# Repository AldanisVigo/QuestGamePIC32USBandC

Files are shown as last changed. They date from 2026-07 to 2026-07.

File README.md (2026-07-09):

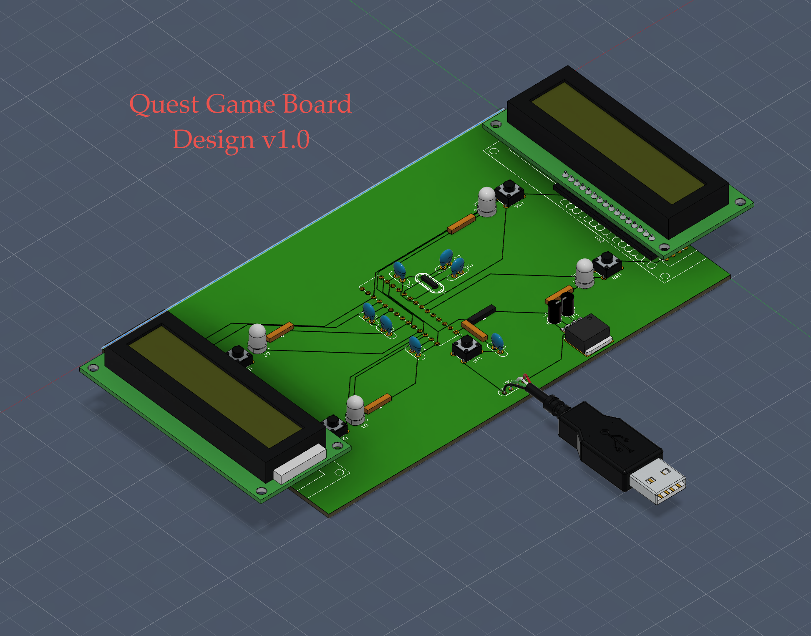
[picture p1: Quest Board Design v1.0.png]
Quest Board Design v1.0


# QuestGamePIC32USBandC

PIC32 USB CDC project with a GTK host game-controller app.

Current baseline:

- PIC32 enumerates as USB CDC serial.
- GTK host app connects over `/dev/cu.usbmodem*`.
- Host app edits and runs a 6-category, 5-row quiz board with a built-in starter trivia deck and A-D answers.
- Category selection alternates between players; the non-chooser is locked during board selection.
- PIC drives two I2C LCD backpacks: player 1 at `0x26`, player 2 at `0x23`.
- PIC stores the active question/options and scrolls player LCD text locally.
- PIC reads four active-low buttons on chip pins `6`, `7`, `11`, and `14`.
- PIC controls four button LEDs on chip pins `16`, `24`, `25`, and `26`, including solid/slow/fast game-state patterns.
- CDC control transfers are acknowledged correctly, so macOS opens the device without the previous timeout.

Default button and LED wiring:

| Button | Switch wire 1 | Switch wire 2 | LED + | LED - |
|---|---:|---:|---:|---:|
| P1 Next | chip pin `6` | `GND` | `3.3V through 470Ω` | chip pin `16` |
| P1 Select | chip pin `7` | `GND` | `3.3V through 470Ω` | chip pin `24` |
| P2 Next | chip pin `11` | `GND` | `3.3V through 470Ω` | chip pin `25` |
| P2 Select | chip pin `14` | `GND` | `3.3V through 470Ω` | chip pin `26` |

LED outputs are active-low: the PIC drives the LED pin low to turn the LED on.

Build:

```sh
cd quest.X
make build

cd ../host/quest-host
make
```

Firmware HEX:

```text
quest.X/dist/default/production/quest.X.production.hex
```

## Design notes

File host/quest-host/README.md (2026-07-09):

# Quest Game Controller

Standalone GTK+ 3 desktop app for running the PIC32 two-player quiz game over USB CDC serial.

## Build

Install GTK+ 3 and `pkg-config`, then build this host project:

```sh
cd host/quest-host
make
```

macOS with Homebrew:

```sh
brew install gtk+3 pkg-config
make
```

Debian/Ubuntu:

```sh
sudo apt install libgtk-3-dev pkg-config
make
```

## Run

```sh
./quest-game-host
```

The app scans common USB CDC serial device paths:

- macOS: `/dev/cu.usbmodem*`, `/dev/cu.usbserial*`
- Linux: `/dev/ttyACM*`, `/dev/ttyUSB*`

## Protocol

Host to PIC:

- `P1:<line1>|<line2>` updates player 1 LCD.
- `P2:<line1>|<line2>` updates player 2 LCD.
- `BOTH:<line1>|<line2>` updates both LCDs.
- `QSET:<question>|<A>|<B>|<C>|<D>` sends one question to the PIC; the PIC scrolls it locally.
- `QSEL:P1:A` or `QSEL:P2:D` changes the displayed answer option for one player.
- `LED:P1:NEXT:ON`, `OFF`, `SLOW`, or `FAST` controls player 1 next LED.
- `LED:P1:SELECT:ON`, `OFF`, `SLOW`, or `FAST` controls player 1 select LED.
- `LED:P2:NEXT:ON`, `OFF`, `SLOW`, or `FAST` controls player 2 next LED.
- `LED:P2:SELECT:ON`, `OFF`, `SLOW`, or `FAST` controls player 2 select LED.

PIC to host:

- `BTN:P1:NEXT`
- `BTN:P1:SELECT`
- `BTN:P2:NEXT`
- `BTN:P2:SELECT`

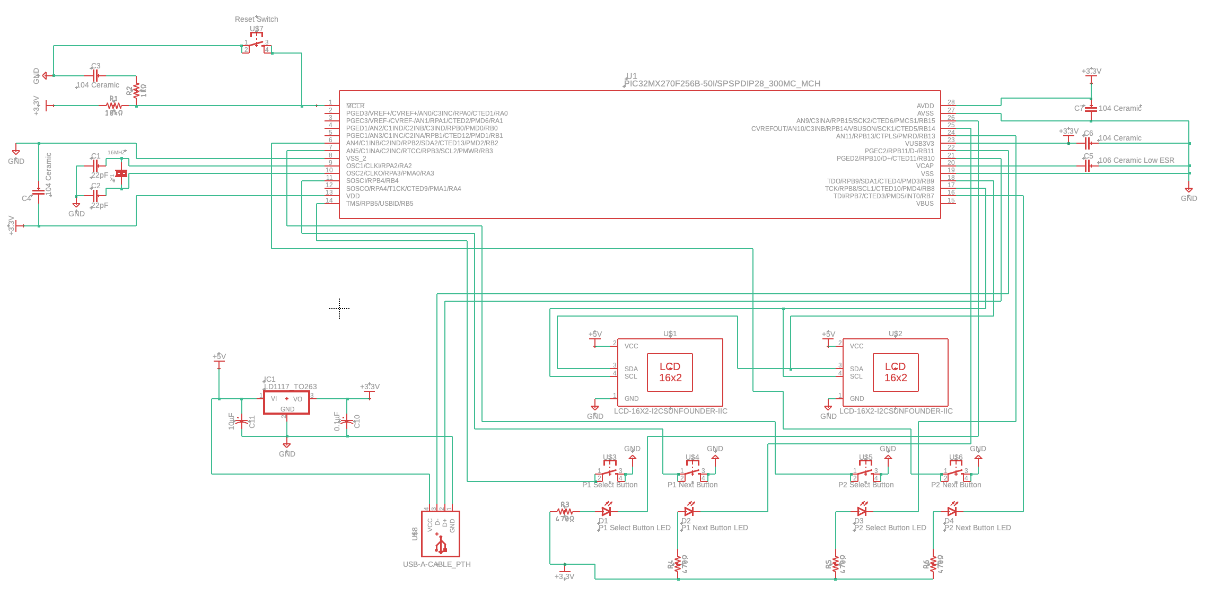
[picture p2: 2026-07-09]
Quest Board Schematic v1.0.png

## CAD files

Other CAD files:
Quest Game Through Hole Single PCB Design v1.0.f3d

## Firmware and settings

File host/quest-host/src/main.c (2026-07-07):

#include <gtk/gtk.h>
#include <stdarg.h>
#include <stdbool.h>
#include <stddef.h>
#include <stdio.h>
#include <string.h>

#include "serial_port.h"

#define SERIAL_BAUD_RATE 115200
#define CATEGORY_COUNT 6
#define AMOUNT_COUNT 5
#define OPTION_COUNT 4
#define PLAYER_COUNT 2
#define LCD_LINE_LENGTH 16
#define SERIAL_RX_BUFFER_SIZE 1024U

typedef enum
{
    GAME_MODE_BOARD,
    GAME_MODE_ANSWER
} GameMode;

typedef enum
{
    PLAYER_ACTION_NEXT,
    PLAYER_ACTION_SELECT
} PlayerAction;

typedef struct
{
    char question[320];
    char options[OPTION_COUNT][96];
    int correct_answer;
    bool used;
} QuestionCell;

typedef struct
{
    int cursor_index;
    int answer_index;
    int selected_answer;
    int score;
    bool answered;
    bool last_correct;
} PlayerState;

typedef struct
{
    GtkWidget *window;
    GtkComboBoxText *device_combo;
    GtkButton *connect_button;
    GtkLabel *status_label;
    GtkLabel *mode_label;
    GtkLabel *score_labels[PLAYER_COUNT];
    GtkLabel *player_status_labels[PLAYER_COUNT];
    GtkEntry *category_entries[CATEGORY_COUNT];
    GtkSpinButton *amount_spins[AMOUNT_COUNT];
    GtkButton *board_buttons[CATEGORY_COUNT][AMOUNT_COUNT];
    GtkLabel *editor_heading_label;
    GtkTextView *question_view;
    GtkTextBuffer *question_buffer;
    GtkEntry *option_entries[OPTION_COUNT];
    GtkComboBoxText *correct_combo;
    GtkButton *save_button;
    GtkButton *start_button;
    GtkButton *reset_button;
    GtkTextView *log_view;
    GtkTextBuffer *log_buffer;

    int serial_fd;
    guint read_timer_id;
    guint connect_watch_id;
    guint result_timeout_id;
    unsigned int connect_generation;
    gint64 connect_started_us;
    bool connecting;

    char serial_rx_buffer[SERIAL_RX_BUFFER_SIZE];
    size_t serial_rx_length;

    char categories[CATEGORY_COUNT][48];
    int amounts[AMOUNT_COUNT];
    QuestionCell cells[CATEGORY_COUNT][AMOUNT_COUNT];
    PlayerState players[PLAYER_COUNT];
    GameMode mode;
    int selected_category;
    int selected_amount;
    int active_category;
    int active_amount;
    int chooser_player;
} AppData;

typedef struct
{
    AppData *app;
    gchar *path;
    int fd;
    unsigned int generation;
    gint64 started_us;
    gint64 worker_started_us;
    gint64 open_returned_us;
    char error[160];
} ConnectRequest;

static gboolean poll_serial(gpointer user_data);
static void refresh_ui(AppData *app);
static void update_all_lcds(AppData *app);
static void load_editor_from_selected(AppData *app);
static void save_editor_to_selected(AppData *app);
static void handle_player_action(AppData *app, int player, PlayerAction action);

static long long elapsed_ms(gint64 start_us, gint64 end_us)
{
    if(start_us <= 0 || end_us < start_us)
    {
        return 0;
    }

    return (long long)((end_us - start_us) / 1000);
}

static GtkWidget *make_icon_label(const char *icon_name, const char *label)
{
    GtkWidget *box = gtk_box_new(GTK_ORIENTATION_HORIZONTAL, 6);
    GtkWidget *image = gtk_image_new_from_icon_name(icon_name, GTK_ICON_SIZE_BUTTON);
    GtkWidget *text = gtk_label_new(label);

    gtk_box_pack_start(GTK_BOX(box), image, FALSE, FALSE, 0);
    gtk_box_pack_start(GTK_BOX(box), text, FALSE, FALSE, 0);

    return box;
}

static void set_button_content(GtkButton *button, const char *icon_name, const char *label)
{
    GtkWidget *child = gtk_bin_get_child(GTK_BIN(button));

    if(child != NULL)
    {
        gtk_container_remove(GTK_CONTAINER(button), child);
    }

    gtk_container_add(GTK_CONTAINER(button), make_icon_label(icon_name, label));
    gtk_widget_show_all(GTK_WIDGET(button));
}

static GtkWidget *new_icon_button(const char *icon_name, const char *tooltip)
{
    GtkWidget *button = gtk_button_new_from_icon_name(icon_name, GTK_ICON_SIZE_BUTTON);
    gtk_widget_set_tooltip_text(button, tooltip);
    return button;
}

static GtkWidget *new_scrolled_text_view(GtkTextView **view, GtkTextBuffer **buffer, int height, bool editable)
{
    GtkWidget *scroll = gtk_scrolled_window_new(NULL, NULL);

    *view = GTK_TEXT_VIEW(gtk_text_view_new());
    *buffer = gtk_text_view_get_buffer(*view);

    gtk_text_view_set_wrap_mode(*view, GTK_WRAP_WORD_CHAR);
    gtk_text_view_set_editable(*view, editable);
    gtk_text_view_set_cursor_visible(*view, editable);
    gtk_container_add(GTK_CONTAINER(scroll), GTK_WIDGET(*view));
    gtk_widget_set_size_request(scroll, -1, height);

    return scroll;
}

static void set_status(AppData *app, const char *message)
{
    gtk_label_set_text(app->status_label, message);
}

static void append_log(AppData *app, const char *prefix, const char *message)
{
    GtkTextIter end;
    GtkTextMark *insert_mark;
    GDateTime *now;
    gchar *clock_text;
    char stamp[32];

    gtk_text_buffer_get_end_iter(app->log_buffer, &end);

    now = g_date_time_new_now_local();
    clock_text = g_date_time_format(now, "%H:%M:%S");
    snprintf(stamp, sizeof(stamp), "[%s.%03d] ", clock_text, g_date_time_get_microsecond(now) / 1000);

    gtk_text_buffer_insert(app->log_buffer, &end, stamp, -1);

    if(prefix != NULL)
    {
        gtk_text_buffer_insert(app->log_buffer, &end, prefix, -1);
    }

    gtk_text_buffer_insert(app->log_buffer, &end, message, -1);
    gtk_text_buffer_insert(app->log_buffer, &end, "\n", -1);

    insert_mark = gtk_text_buffer_get_insert(app->log_buffer);
    gtk_text_view_scroll_mark_onscreen(app->log_view, insert_mark);

    g_free(clock_text);
    g_date_time_unref(now);
}

static void append_logf(AppData *app, const char *prefix, const char *format, ...)
{
    va_list args;
    gchar *message;

    va_start(args, format);
    message = g_strdup_vprintf(format, args);
    va_end(args);

    append_log(app, prefix, message);
    g_free(message);
}

static const char *player_action_name(PlayerAction action)
{
    return action == PLAYER_ACTION_NEXT ? "NEXT" : "SELECT";
}

static const char *game_mode_name(GameMode mode)
{
    return mode == GAME_MODE_BOARD ? "board" : "answer";
}

static int next_player_index(int player)
{
    return (player + 1) % PLAYER_COUNT;
}

static void copy_text(char *dest, size_t dest_size, const char *source)
{
    if(source == NULL)
    {
        source = "";
    }

    g_strlcpy(dest, source, dest_size);
}

static int cell_index(int category, int amount)
{
    return (amount * CATEGORY_COUNT) + category;
}

static void cell_from_index(int index, int *category, int *amount)
{
    if(index < 0)
    {
        index = 0;
    }

    *category = index % CATEGORY_COUNT;
    *amount = index / CATEGORY_COUNT;
}

static QuestionCell *cell_at(AppData *app, int category, int amount)
{
    return &app->cells[category][amount];
}

static QuestionCell *selected_cell(AppData *app)
{
    return cell_at(app, app->selected_category, app->selected_amount);
}

static bool cell_is_available(AppData *app, int index)
{
    int category;
    int amount;

    if(index < 0 || index >= (CATEGORY_COUNT * AMOUNT_COUNT))
    {
        return false;
    }

    cell_from_index(index, &category, &amount);
    return !cell_at(app, category, amount)->used;
}

static int find_available_cell(AppData *app, int start_index, int direction)
{
    const int total = CATEGORY_COUNT * AMOUNT_COUNT;

    if(direction == 0)
    {
        direction = 1;
    }

    for(int step = 0; step < total; step++)
    {
        int index = (start_index + (step * direction)) % total;

        if(index < 0)
        {
            index += total;
        }

        if(cell_is_available(app, index))
        {
            return index;
        }
    }

    return -1;
}

static void reset_player_cursors(AppData *app)
{
    int first = find_available_cell(app, 0, 1);

    for(int player = 0; player < PLAYER_COUNT; player++)
    {
        app->players[player].cursor_index = first;
        app->players[player].answer_index = 0;
        app->players[player].selected_answer = -1;
        app->players[player].answered = false;
        app->players[player].last_correct = false;
    }
}

static void game_init_content(AppData *app)
{
    typedef struct
    {
        const char *question;
        const char *options[OPTION_COUNT];
        int correct_answer;
    } DefaultQuestion;

    static const char *default_categories[CATEGORY_COUNT] =
    {
        "Science",
        "History",
        "Geography",
        "Movies",
        "Tech",
        "Games"
    };

    static const DefaultQuestion default_questions[CATEGORY_COUNT][AMOUNT_COUNT] =
    {
        {
            {
                "What gas do plants absorb from the air during photosynthesis?",
                { "Oxygen", "Carbon dioxide", "Nitrogen", "Helium" },
                1
            },
            {
                "What force pulls objects toward the center of Earth?",
                { "Magnetism", "Friction", "Gravity", "Electricity" },
                2
            },
            {
                "What is the chemical formula for water?",
                { "CO2", "H2O", "O2", "NaCl" },
                1
            },
            {
                "Which planet is often called the Red Planet?",
                { "Venus", "Jupiter", "Mars", "Mercury" },
                2
            },
            {
                "What is the smallest basic unit of living organisms?",
                { "Atom", "Cell", "Organ", "Tissue" },
                1
            }
        },
        {
            {
                "Who was the first president of the United States?",
                { "John Adams", "Thomas Jefferson", "George Washington", "James Madison" },
                2
            },
            {
                "Which wall fell in 1989, becoming a symbol of the Cold War ending?",
                { "Hadrian's Wall", "Berlin Wall", "Great Wall", "Western Wall" },
                1
            },
            {
                "Which ancient civilization built the pyramids at Giza?",
                { "Romans", "Egyptians", "Vikings", "Aztecs" },
                1
            },
            {
                "Which American document begins with the words 'We the People'?",
                { "Declaration of Independence", "Bill of Rights", "U.S. Constitution", "Gettysburg Address" },
                2
            },
            {
                "What ship carried the Pilgrims to New England in 1620?",
                { "Santa Maria", "Mayflower", "Endeavour", "Beagle" },
                1
            }
        },
        {
            {
                "What is the largest ocean on Earth?",
                { "Atlantic", "Indian", "Arctic", "Pacific" },
                3
            },
            {
                "Which country is famously shaped like a boot?",
                { "Italy", "Greece", "Chile", "Portugal" },
                0
            },
            {
                "Which river runs through Egypt and helped support its ancient civilization?",
                { "Amazon", "Danube", "Nile", "Ganges" },
                2
            },
            {
                "What is the capital city of Japan?",
                { "Kyoto", "Tokyo", "Osaka", "Sapporo" },
                1
            },
            {
                "What is the highest mountain above sea level?",
                { "K2", "Denali", "Mount Everest", "Kilimanjaro" },
                2
            }
        },
        {
            {
                "Which movie franchise is known for Jedi and lightsabers?",
                { "Star Trek", "Star Wars", "The Matrix", "Avatar" },
                1
            },
            {
                "What is the name of Harry Potter's school?",
                { "Hogwarts", "Narnia", "Nevermore", "Rivendell" },
                0
            },
            {
                "Which Disney movie features sisters named Elsa and Anna?",
                { "Moana", "Frozen", "Tangled", "Brave" },
                1
            },
            {
                "What fictional city is protected by Batman?",
                { "Metropolis", "Gotham City", "Central City", "Star City" },
                1
            },
            {
                "Which actor made the line 'I'll be back' famous in The Terminator?",
                { "Bruce Willis", "Sylvester Stallone", "Arnold Schwarzenegger", "Harrison Ford" },
                2
            }
        },
        {
            {
                "What does CPU stand for?",
                { "Central Processing Unit", "Computer Power Utility", "Core Program Update", "Control Panel Unit" },
                0
            },
            {
                "Binary numbers use which base?",
                { "Base 8", "Base 10", "Base 16", "Base 2" },
                3
            },
            {
                "Which protocol is the foundation for loading most web pages?",
                { "HTTP", "MIDI", "SMTP", "GPS" },
                0
            },
            {
                "What sensor measures acceleration?",
                { "Thermistor", "Accelerometer", "Barometer", "Photodiode" },
                1
            },
            {
                "What does ROM usually stand for in electronics?",
                { "Random Output Module", "Read-Only Memory", "Remote Operating Mode", "Runtime Object Map" },
                1
            }
        },
        {
            {
                "How many points is a touchdown worth in American football?",
                { "3", "6", "7", "10" },
                1
            },
            {
                "Which chess piece moves in an L shape?",
                { "Bishop", "Rook", "Knight", "Queen" },
                2
            },
            {
                "How often are the Summer Olympic Games normally held?",
                { "Every 2 years", "Every 3 years", "Every 4 years", "Every 5 years" },
                2
            },
            {
                "Which board game has players buy properties and collect rent?",
                { "Monopoly", "Risk", "Clue", "Scrabble" },
                0
            },
            {
                "In tennis, what is the score called after deuce when one player wins the next point?",
                { "Match", "Break", "Advantage", "Set" },
                2
            }
        }
    };

    for(int category = 0; category < CATEGORY_COUNT; category++)
    {
        copy_text(app->categories[category], sizeof(app->categories[category]), default_categories[category]);
    }

    for(int amount = 0; amount < AMOUNT_COUNT; amount++)
    {
        app->amounts[amount] = (amount + 1) * 100;
    }

    for(int category = 0; category < CATEGORY_COUNT; category++)
    {
        for(int amount = 0; amount < AMOUNT_COUNT; amount++)
        {
            QuestionCell *cell = cell_at(app, category, amount);
            const DefaultQuestion *question = &default_questions[category][amount];

            copy_text(cell->question, sizeof(cell->question), question->question);
            for(int option = 0; option < OPTION_COUNT; option++)
            {
                copy_text(cell->options[option],
                          sizeof(cell->options[option]),
                          question->options[option]);
            }
            cell->correct_answer = question->correct_answer;
            cell->used = false;
        }
    }

    app->selected_category = 0;
    app->selected_amount = 0;
    app->active_category = 0;
    app->active_amount = 0;
    app->mode = GAME_MODE_BOARD;
    app->chooser_player = 0;
    app->players[0].score = 0;
    app->players[1].score = 0;
    reset_player_cursors(app);
}

static void lcd_clean_line(const char *source, char *dest)
{
    size_t length = 0;

    if(source == NULL)
    {
        source = "";
    }

    while(source[length] != '\0' && length < LCD_LINE_LENGTH)
    {
        unsigned char c = (unsigned char)source[length];

        if(c == '|' || c == '\r' || c == '\n' || c == '\t')
        {
            dest[length] = ' ';
        }
        else if(c >= 32U && c <= 126U)
        {
            dest[length] = (char)c;
        }
        else
        {
            dest[length] = '?';
        }

        length++;
    }

    dest[length] = '\0';
}

static void send_lcd_lines_internal(AppData *app,
                                    int player,
                                    const char *line1,
                                    const char *line2,
                                    bool log_command)
{
    char clean1[LCD_LINE_LENGTH + 1U];
    char clean2[LCD_LINE_LENGTH + 1U];
    char command[64];
    char preview[64];
    char error[160];

    if(app->serial_fd < 0)
    {
        return;
    }

    lcd_clean_line(line1, clean1);
    lcd_clean_line(line2, clean2);

    snprintf(command, sizeof(command), "P%d:%s|%s\n", player + 1, clean1, clean2);
    g_strlcpy(preview, command, sizeof(preview));
    g_strchomp(preview);

    if(log_command)
    {
        append_logf(app, "> ", "%s", preview);
    }

    if(pic_serial_write_all(app->serial_fd, command, strlen(command), 350, error, sizeof(error)) != 0)
    {
        append_log(app, "! ", error);
        set_status(app, "LCD write failed");
    }
}

static void send_led_command(AppData *app, int player, const char *button_name, const char *mode)
{
    char command[40];
    char error[160];

    if(app->serial_fd < 0)
    {
        return;
    }

    snprintf(command, sizeof(command), "LED:P%d:%s:%s\n",
             player + 1,
             button_name,
             mode);

    if(pic_serial_write_all(app->serial_fd, command, strlen(command), 250, error, sizeof(error)) != 0)
    {
        append_log(app, "! ", error);
        set_status(app, "LED write failed");
    }
}

static void append_pic_protocol_field(GString *command, const char *text)
{
    if(text == NULL)
    {
        text = "";
    }

    for(const unsigned char *cursor = (const unsigned char *)text; *cursor != '\0'; cursor++)
    {
        unsigned char c = *cursor;

        if(c == '|' || c == '\r' || c == '\n' || c == '\t')
        {
            g_string_append_c(command, ' ');
        }
        else if(c >= 32U && c <= 126U)
        {
            g_string_append_c(command, (char)c);
        }
        else
        {
            g_string_append_c(command, '?');
        }
    }
}

static void send_question_set_command(AppData *app)
{
    QuestionCell *cell = cell_at(app, app->active_category, app->active_amount);
    GString *command;
    char error[160];

    if(app->serial_fd < 0)
    {
        return;
    }

    command = g_string_new("QSET:");
    append_pic_protocol_field(command, cell->question);

    for(int option = 0; option < OPTION_COUNT; option++)
    {
        g_string_append_c(command, '|');
        append_pic_protocol_field(command, cell->options[option]);
    }

    g_string_append_c(command, '\n');
    append_logf(app, "> ", "QSET question/options (%zu byte(s))", command->len);

    if(pic_serial_write_all(app->serial_fd, command->str, command->len, 1500, error, sizeof(error)) != 0)
    {
        append_log(app, "! ", error);
        set_status(app, "Question write failed");
    }

    g_string_free(command, TRUE);
}

static void send_question_select_command(AppData *app, int player)
{
    char command[16];
    char error[160];

    if(app->serial_fd < 0 || player < 0 || player >= PLAYER_COUNT)
    {
        return;
    }

    snprintf(command, sizeof(command), "QSEL:P%d:%c\n",
             player + 1,
             'A' + app->players[player].answer_index);

    append_logf(app, "> ", "QSEL:P%d:%c", player + 1, 'A' + app->players[player].answer_index);

    if(pic_serial_write_all(app->serial_fd, command, strlen(command), 250, error, sizeof(error)) != 0)
    {
        append_log(app, "! ", error);
        set_status(app, "Answer display write failed");
    }
}

static void update_leds_for_player(AppData *app, int player)
{
    const char *next_mode = "OFF";
    const char *select_mode = "OFF";

    if(player < 0 || player >= PLAYER_COUNT)
    {
        return;
    }

    if(app->mode == GAME_MODE_BOARD)
    {
        if(app->players[player].cursor_index >= 0 && player == app->chooser_player)
        {
            next_mode = "SLOW";
            select_mode = "FAST";
        }
    }
    else if(!app->players[player].answered)
    {
        next_mode = "ON";
        select_mode = "FAST";
    }
    else
    {
        next_mode = app->players[player].last_correct ? "FAST" : "SLOW";
        select_mode = app->players[player].last_correct ? "FAST" : "SLOW";
    }

    send_led_command(app, player, "NEXT", next_mode);
    send_led_command(app, player, "SELECT", select_mode);
}
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
int main(int argc, char **argv)
{
    AppData app;

    memset(&app, 0, sizeof(app));
    app.serial_fd = -1;

    game_init_content(&app);

    gtk_init(&argc, &argv);
    build_ui(&app);
    refresh_ports(&app);

    gtk_widget_show_all(app.window);
    gtk_main();

    disconnect_device(&app);

    return 0;
}

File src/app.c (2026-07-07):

#include "app.h"
#include "definitions.h"
#include "../quest.X/lcd_i2c.h"
#include <stdbool.h>
#include <stddef.h>
#include <stdint.h>
#include <string.h>

#define APP_READ_BUFFER_SIZE 64U
#define APP_WRITE_BUFFER_SIZE 64U
#define APP_LCD_COLUMNS 16U
#define APP_COMMAND_BUFFER_SIZE 768U
#define APP_TX_QUEUE_COUNT 10U
#define APP_TX_QUEUE_MESSAGE_SIZE 64U
#define APP_PLAYER_COUNT 2U
#define APP_OPTION_COUNT 4U
#define APP_QUESTION_TEXT_SIZE 241U
#define APP_OPTION_TEXT_SIZE 81U
#define APP_SCROLL_WINDOW_CHARS (APP_LCD_COLUMNS - 2U)
#define APP_SCROLL_GAP 4U
#define APP_DISPLAY_SCROLL_COUNTS (CPU_CLOCK_FREQUENCY / 2U)
#define APP_LED_TASK_COUNTS (CPU_CLOCK_FREQUENCY / 8U)
#define APP_LED_SLOW_DIVIDER 4U

#define APP_PLAYER1_LCD_ADDRESS 0x26U
#define APP_PLAYER2_LCD_ADDRESS 0x23U

/*
 * Default button wiring:
 *   P1 next/select: chip pins 6/7  (RB2/RB3)
 *   P2 next/select: chip pins 11/14 (RB4/RB5)
 *
 * Default LED wiring:
 *   P1 next/select LED cathodes: chip pins 16/24 (RB7/RB13)
 *   P2 next/select LED cathodes: chip pins 25/26 (RB14/RB15)
 *
 * Wire each button between the pin and GND. The firmware enables weak pull-ups,
 * so a pressed button reads low. Wire each LED anode to 3.3V through a
 * current-limiting resistor; the firmware sinks current to turn LEDs on.
 */
#define APP_BUTTON_P1_NEXT_MASK   (1UL << 2)
#define APP_BUTTON_P1_SELECT_MASK (1UL << 3)
#define APP_BUTTON_P2_NEXT_MASK   (1UL << 4)
#define APP_BUTTON_P2_SELECT_MASK (1UL << 5)
#define APP_BUTTON_MASK (APP_BUTTON_P1_NEXT_MASK | APP_BUTTON_P1_SELECT_MASK | \
                         APP_BUTTON_P2_NEXT_MASK | APP_BUTTON_P2_SELECT_MASK)
#define APP_LED_P1_NEXT_MASK      (1UL << 7)
#define APP_LED_P1_SELECT_MASK    (1UL << 13)
#define APP_LED_P2_NEXT_MASK      (1UL << 14)
#define APP_LED_P2_SELECT_MASK    (1UL << 15)
#define APP_LED_MASK (APP_LED_P1_NEXT_MASK | APP_LED_P1_SELECT_MASK | \
                      APP_LED_P2_NEXT_MASK | APP_LED_P2_SELECT_MASK)
#define APP_BUTTON_POLL_COUNTS (CPU_CLOCK_FREQUENCY / 500U)
#define APP_BUTTON_DEBOUNCE_COUNTS (CPU_CLOCK_FREQUENCY / 50U)

typedef struct
{
    uint32_t mask;
    const char *eventText;
} APP_BUTTON_EVENT;

typedef enum
{
    APP_LED_MODE_OFF,
    APP_LED_MODE_ON,
    APP_LED_MODE_SLOW,
    APP_LED_MODE_FAST
} APP_LED_MODE;

typedef struct
{
    uint32_t mask;
    APP_LED_MODE mode;
} APP_LED_CONTROL;

static USB_DEVICE_HANDLE usbDeviceHandle = USB_DEVICE_HANDLE_INVALID;
static USB_DEVICE_CDC_TRANSFER_HANDLE readTransferHandle;
static USB_DEVICE_CDC_TRANSFER_HANDLE writeTransferHandle;
static USB_DEVICE_CDC_TRANSFER_HANDLE serialStateTransferHandle;
static size_t readLength = 0;

static bool deviceConfigured = false;
static bool readComplete = false;
static bool writeComplete = true;
static bool readyMessagesQueued = false;
static bool lcdAddressesPrepared = false;
static bool serialStateNotificationPending = false;
static bool serialStateNotificationBusy = false;

static uint8_t readBuffer[APP_READ_BUFFER_SIZE] __attribute__((coherent, aligned(16)));
static uint8_t writeBuffer[APP_WRITE_BUFFER_SIZE] __attribute__((coherent, aligned(16)));

static char txQueue[APP_TX_QUEUE_COUNT][APP_TX_QUEUE_MESSAGE_SIZE];
static uint8_t txQueueHead = 0;
static uint8_t txQueueTail = 0;
static uint8_t txQueueCount = 0;

static char pendingCommand[APP_COMMAND_BUFFER_SIZE];
static size_t pendingCommandLength = 0;
static bool pendingCommandTruncated = false;

static const uint8_t playerLcdAddresses[APP_PLAYER_COUNT] =
{
    APP_PLAYER1_LCD_ADDRESS,
    APP_PLAYER2_LCD_ADDRESS
};

static bool playerLcdInitialized[APP_PLAYER_COUNT] =
{
    false,
    false
};

static const APP_BUTTON_EVENT buttonEvents[] =
{
    { APP_BUTTON_P1_NEXT_MASK,   "BTN:P1:NEXT\r\n" },
    { APP_BUTTON_P1_SELECT_MASK, "BTN:P1:SELECT\r\n" },
    { APP_BUTTON_P2_NEXT_MASK,   "BTN:P2:NEXT\r\n" },
    { APP_BUTTON_P2_SELECT_MASK, "BTN:P2:SELECT\r\n" }
};

static APP_LED_CONTROL ledControls[] =
{
    { APP_LED_P1_NEXT_MASK,   APP_LED_MODE_OFF },
    { APP_LED_P1_SELECT_MASK, APP_LED_MODE_OFF },
    { APP_LED_P2_NEXT_MASK,   APP_LED_MODE_OFF },
    { APP_LED_P2_SELECT_MASK, APP_LED_MODE_OFF }
};

static uint32_t buttonLastPollCount = 0;
static uint32_t buttonLastChangeCount = 0;
static uint32_t buttonLastRawPressedMask = 0;
static uint32_t buttonStablePressedMask = 0;
static uint32_t ledLastTaskCount = 0;
static uint8_t ledSlowDivider = 0;
static bool ledFastPhase = false;
static bool ledSlowPhase = false;

static char displayQuestion[APP_QUESTION_TEXT_SIZE];
static char displayOptions[APP_OPTION_COUNT][APP_OPTION_TEXT_SIZE];
static bool playerQuestionDisplayActive[APP_PLAYER_COUNT] =
{
    false,
    false
};
static uint8_t playerQuestionAnswerIndex[APP_PLAYER_COUNT] =
{
    0,
    0
};
static uint16_t displayQuestionScrollTick = 0;
static uint16_t playerOptionScrollTick[APP_PLAYER_COUNT] =
{
    0,
    0
};
static uint8_t displayNextScrollPlayer = 0;
static uint32_t displayLastScrollCount = 0;

static USB_CDC_LINE_CODING lineCoding __attribute__((coherent, aligned(16))) =
{
    115200,
    0,
    0,
    8
};

static USB_CDC_SERIAL_STATE serialState __attribute__((coherent, aligned(16))) =
{
    .bRxCarrier = 1,
    .bTxCarrier = 1,
    .bBreak = 0,
    .bRingSignal = 0,
    .bFraming = 0,
    .bParity = 0,
    .bOverRun = 0
};

static void APP_USBDeviceEventHandler(USB_DEVICE_EVENT event, void *eventData, uintptr_t context);

static void APP_USBResetTxQueue(void)
{
    txQueueHead = 0;
    txQueueTail = 0;
    txQueueCount = 0;
}

static bool APP_USBQueueString(const char *message)
{
    size_t length;

    if(txQueueCount >= APP_TX_QUEUE_COUNT)
    {
        return false;
    }

    length = strlen(message);
    if(length >= APP_TX_QUEUE_MESSAGE_SIZE)
    {
        length = APP_TX_QUEUE_MESSAGE_SIZE - 1U;
    }

    memcpy(txQueue[txQueueTail], message, length);
    txQueue[txQueueTail][length] = '\0';

    txQueueTail = (uint8_t)((txQueueTail + 1U) % APP_TX_QUEUE_COUNT);
    txQueueCount++;

    return true;
}
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

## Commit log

2026-07-09 Added board design image to the repo readme
2026-07-09 Added schematic and board deisgn files to the repo
    [Quest Game Through Hole Single PCB Design v1.0.f3d]
2026-07-09 Added schematic image to the repo
